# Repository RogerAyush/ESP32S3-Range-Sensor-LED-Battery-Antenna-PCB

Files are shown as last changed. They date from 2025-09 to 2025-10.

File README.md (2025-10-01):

# 🚀 ESP32-S3 Vision Board with Camera and ToF Sensor

A custom all-in-one development board for vision and sensing applications.
This compact **4-layer PCB** integrates the **ESP32-S3** microcontroller, **OV5640** camera module, **VL53L0X Time-of-Flight (ToF)** sensor connector, wireless connectivity, and portable power management. It eliminates the need for separate breakouts and jumper wires, enabling clean setups for prototyping **AI cameras**, gesture-controlled devices, or battery-powered drones.

The design is based on the **ESP32-S3R8 SoC**, featuring dual-core processing up to **240 MHz**, **Wi-Fi 4**, **Bluetooth 5** (including LE), and hardware acceleration for **AI tasks**. It supports edge computing with the camera's **5 MP resolution** (up to **1080p at 30 fps**) and the ToF sensor's precise distance ranging up to **2 m**.

---

## 🌟 Key Features
- **Camera Support**: **24-pin FPC** for OV5640; DVP data (Y2-Y9, HREF, VSYNC, PCLK) + I²C (IO39/IO40); **2.8V LDO** (MIC5504) + enable pin (IO33) for power management.
- **ToF Sensor**: **6-pin FPC** (J3) for VL53L0X; I²C (IO4/IO5) with **4.7 kΩ pull-ups** + drain/power connections.
- **Wireless**: PCB antenna + LNA matching (**35 + j10 Ω**); U.FL (J2) for external antenna; **40 MHz crystal** for stable clocking.
- **Power System**: **USB-C** (5V input/programming); LiPo charger (**MCP73831**, ~**417 mA**, status LED); P-MOSFET switching; buck converter to **3.3V** (U1); LDOs for **1.8V/2.8V**; Schottky diode (**D3**) protection.
- **Storage**: **8 MB QSPI Flash** (**GD25Q64**) for firmware and data logging.
- **User Interface**: 4 switches (**SW1-SW4**: EN reset, BOOT mode, IO8/IO9 buttons); green LEDs (**D2/D5** on IO45/IO46) for status indication.
- **Debug**: USB routed to **U0TXD/RXD** for serial output; **JTAG** pins exposed.
- **Size & Build**: ~**50 x 40 mm** 4-layer FR4 (**1.6 mm thick**, **1 oz Cu**); **ENIG finish**; full decoupling (**100 nF + ceramics**) near power pins.

---

## ☕ Quick Setup Overview
Connect via **USB-C** and press the **BOOT** switch to program using **ESP-IDF** or **Arduino IDE**. The camera captures frames, streaming video over **Wi-Fi** to a connected device. Attach the ToF sensor to measure distances and trigger actions, such as gestures. Insert a **LiPo battery** for untethered operation lasting several hours. This streamlined process supports rapid iteration and reliable performance.

---

## ⚡ Design Notes
- **Power Flow**: USB or battery input to **VIN** (~**4.6 V** after diode), stepped down to **3.3 V** via buck converter for the ESP32; LDOs provide **2.8 V** for the camera and other analog rails. Camera power is gated by **P-FET (U2)** on IO33—high to enable, low for sleep modes.
- **Signal Integrity**: DVP traces length-matched with ~**90 Ω differential impedance**; SPI to Flash kept short (<**50 Ω**); RF section isolated using ground pours.
- **Protections**: **TVS diode (D1)** on USB lines, ferrite beads (**FB1, L4**) for EMI filtering; pull-ups/downs on critical pins (e.g., **10 kΩ** on EN/BOOT).
- **Current Draw**: Idle ~**50 mA**; full camera + Wi-Fi operation ~**250 mA**. Compatible with **3.7 V LiPo cells** up to **1000 mAh**.
- **Tools Used**: Designed in **Altium Designer** (schematic dated **10-01-2025**). SPICE simulations verified charger current ($I_{CHG} = 1000/2.4k \approx 417 \text{ mA}$) and switching behavior.

---

## 📁 Repo Contents
- **Schematics**: Full Altium project (**Sheet.SchDoc**) and exported PDF (**Print.pdf**) covering all sheets (power, camera/ToF, USB, etc.).
- **BOM**: CSV with part numbers, values, and footprints (e.g., **ESP32-S3R8**, **MIC5504-2.8YM5** for camera LDO).
- **Gerbers & Files**: PCB layout, drill files, and Pick & Place data for fabrication.
- **3D Renders**: STEP models and layer views (top/bottom/inners) for detailed inspection.
- **Firmware Snippets**: Basic **ESP-IDF** examples for camera initialization, ToF polling, and Wi-Fi streaming.

---

## 🖼️ PCB Layout and 3D View

Here are the renders of the 4-layer PCB design and a 3D model of the assembled board.

**Top Layer View**
*The top layer is densely populated with the main components, including the ESP32-S3, camera/ToF connectors, USB-C port, and power management ICs.*


**Bottom Layer View**
*The bottom layer has the LiPo Battery Connector.*


**Inner Layers (Power & Ground)**
*The inner layers consist of a dedicated ground plane and a power plane to ensure signal integrity and proper power distribution.*


**3D Render**
*A 3D render of the assembled board provides a complete view of the final product.*


---

Print_page-0001

*(Comprehensive schematic from Altium, including battery charger, voltage regulators, power switching, camera/ToF connectors, and supporting circuits.)*

For layer details, refer to the PDF: top layer features **ESP32** and connectors; inner layers handle power and ground planes; bottom layer includes **RF** and passives.

---

## 📅 Status & Next Steps
Design is complete and Gerber-ready as of **October 1, 2025**. Prototypes are in production—expect assembly and validation tests (camera focus, ToF accuracy, battery runtime) by month-end. Version 2 will include the **ToF flex PCB** and potential **IMU expansion**.

Download the files, fabricate a board, and explore applications like drone vision or smart mirrors. Contributions via issues or pull requests are welcome. For questions, reach out.

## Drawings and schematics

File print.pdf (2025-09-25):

# ESP32 WITH CAM and TOF

## LiPo Battery Charger 1 cell

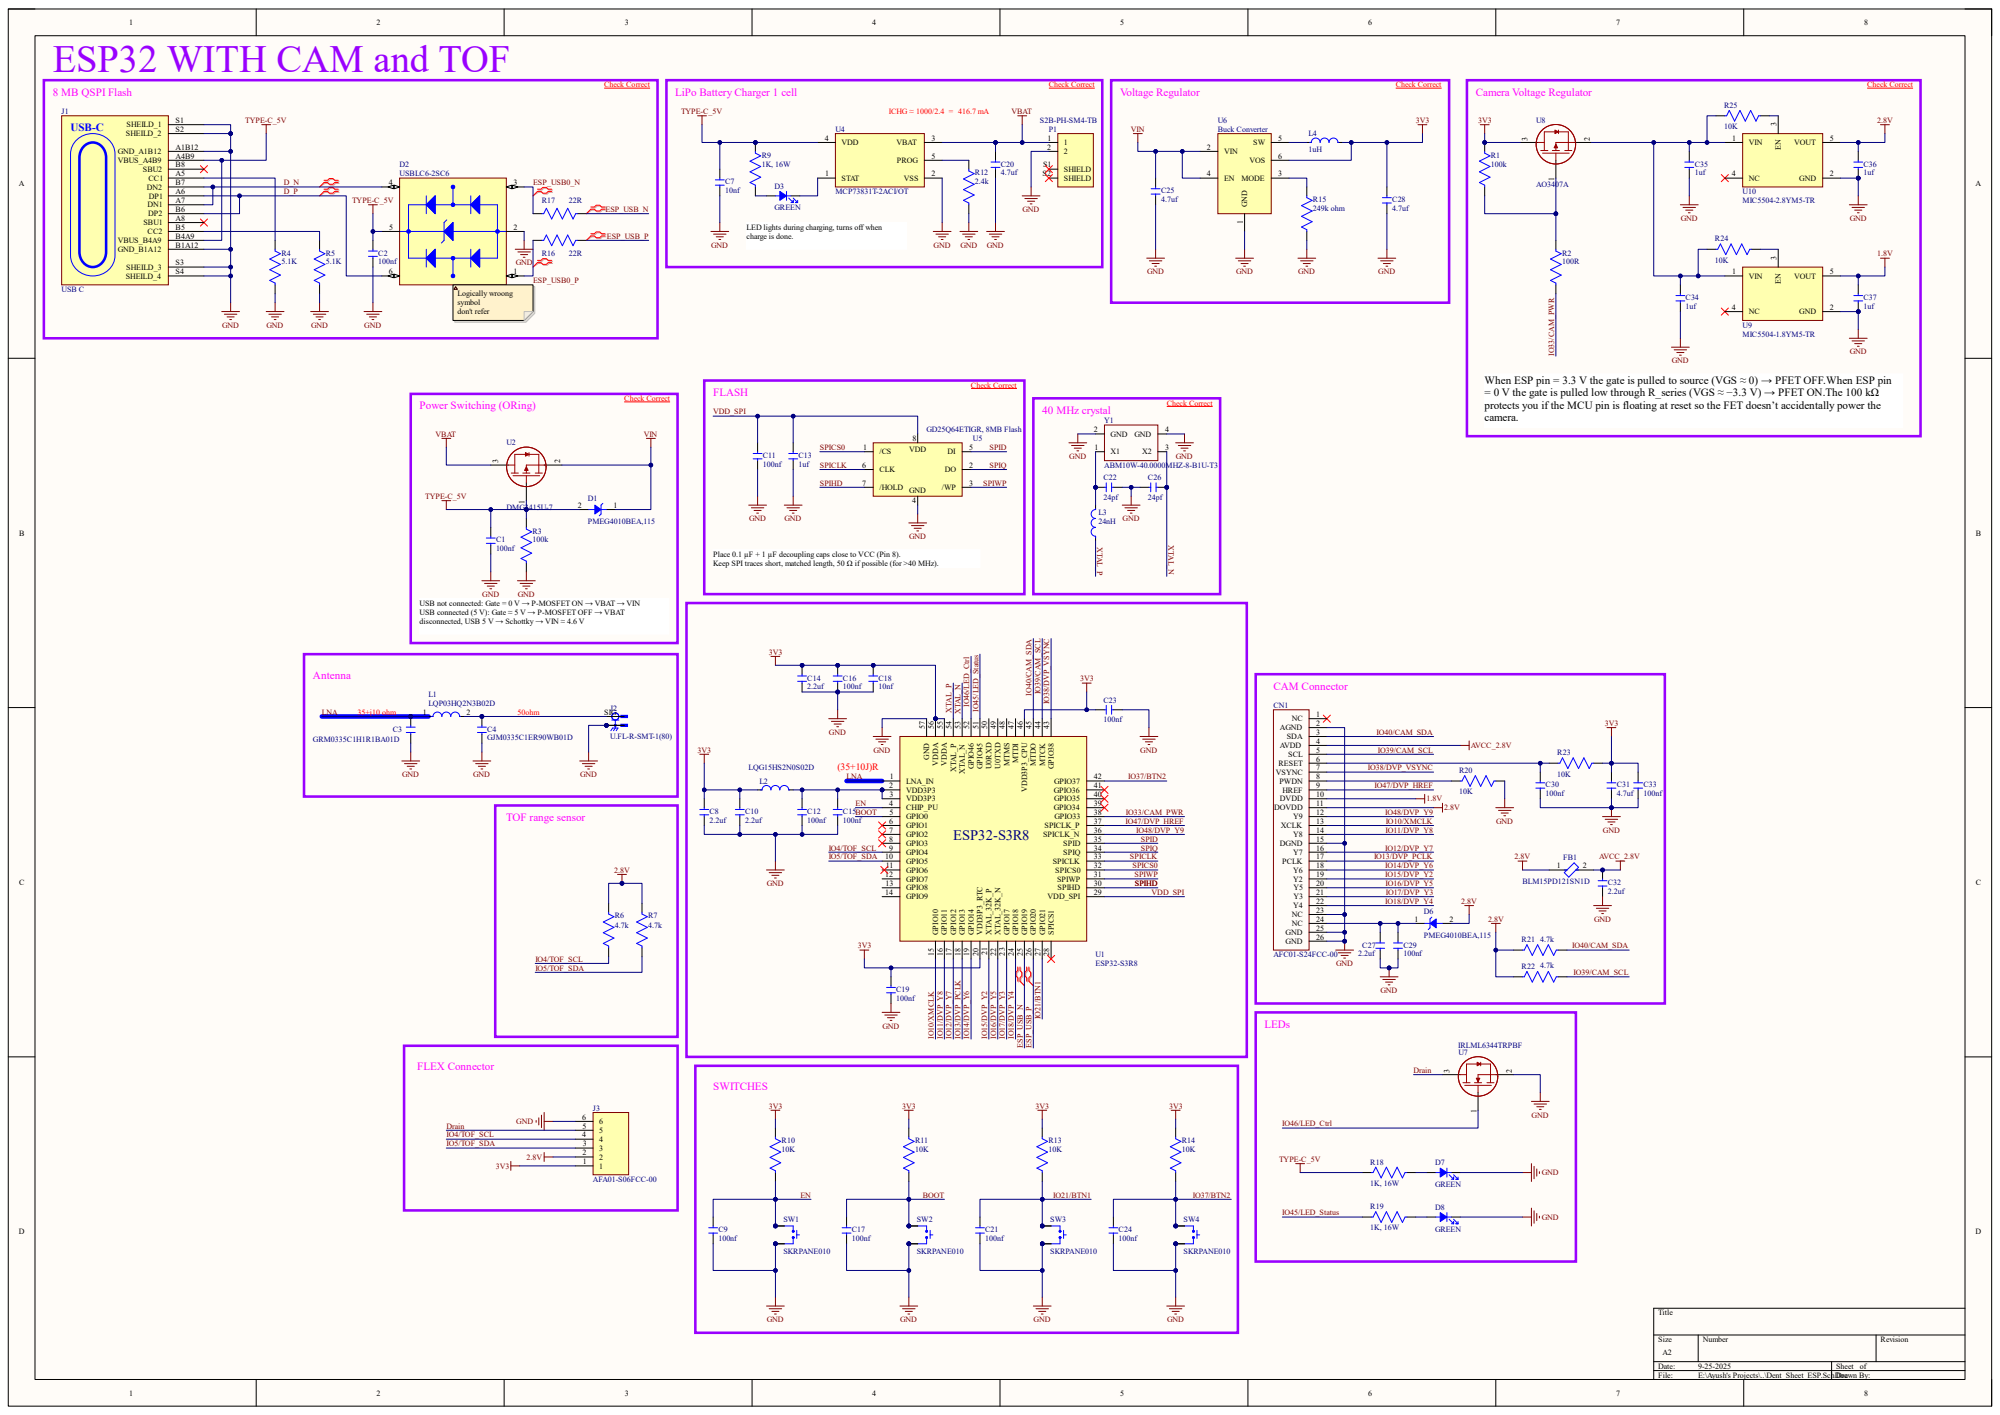
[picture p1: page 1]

LED lights during charging, turns off when
charge is done.

When ESP pin = 3.3 V the gate is pulled to source (VGS ≈ 0) → PFET OFF.When ESP pin
= 0 V the gate is pulled low through R_series (VGS ≈ −3.3 V) → PFET ON.The 100 kΩ
protects you if the MCU pin is floating at reset so the FET doesn’t accidentally power the
camera.

Place 0.1 µF + 1 µF decoupling caps close to VCC (Pin 8).
Keep SPI traces short, matched length, 50 Ω if possible (for >40 MHz).

USB not connected: Gate = 0 V → P-MOSFET ON → VBAT → VIN
USB connected (5 V): Gate ≈ 5 V → P-MOSFET OFF → VBAT
disconnected, USB 5 V → Schottky → VIN ≈ 4.6 V
